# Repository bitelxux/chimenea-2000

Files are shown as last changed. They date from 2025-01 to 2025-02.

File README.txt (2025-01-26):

# libraries proved to work

Used library      Version Path
ArduinoJson       5.13.5  /home/cnn/Arduino/libraries/ArduinoJson
btlx25                    /home/cnn/MEGA/dev/arduino/btlx25
ESP8266WiFi       1.0     /home/cnn/.arduino15/packages/esp8266/hardware/esp8266/3.1.2/libraries/ESP8266WiFi
ESP8266HTTPClient 1.2     /home/cnn/.arduino15/packages/esp8266/hardware/esp8266/3.1.2/libraries/ESP8266HTTPClient
ArduinoOTA        1.0     /home/cnn/.arduino15/packages/esp8266/hardware/esp8266/3.1.2/libraries/ArduinoOTA
EEPROM            1.0     /home/cnn/.arduino15/packages/esp8266/hardware/esp8266/3.1.2/libraries/EEPROM
NTPClient         3.2.1   /home/cnn/Arduino/libraries/NTPClient
DNSServer         1.1.1   /home/cnn/.arduino15/packages/esp8266/hardware/esp8266/3.1.2/libraries/DNSServer
ESP8266WebServer  1.0     /home/cnn/.arduino15/packages/esp8266/hardware/esp8266/3.1.2/libraries/ESP8266WebServer
WiFiManager       2.0.17  /home/cnn/Arduino/libraries/WiFiManager
ESP8266mDNS       1.2     /home/cnn/.arduino15/packages/esp8266/hardware/esp8266/3.1.2/libraries/ESP8266mDNS

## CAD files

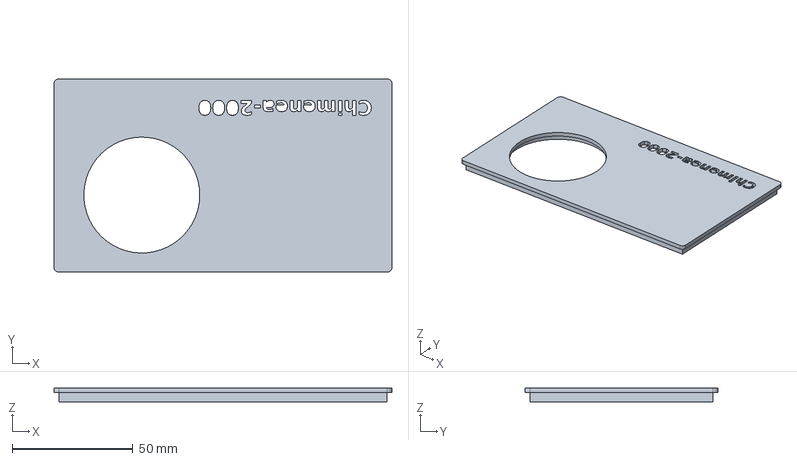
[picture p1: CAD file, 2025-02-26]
freecad/chimenea2000.FCStd
140.0 x 80.0 x 6.00 mm

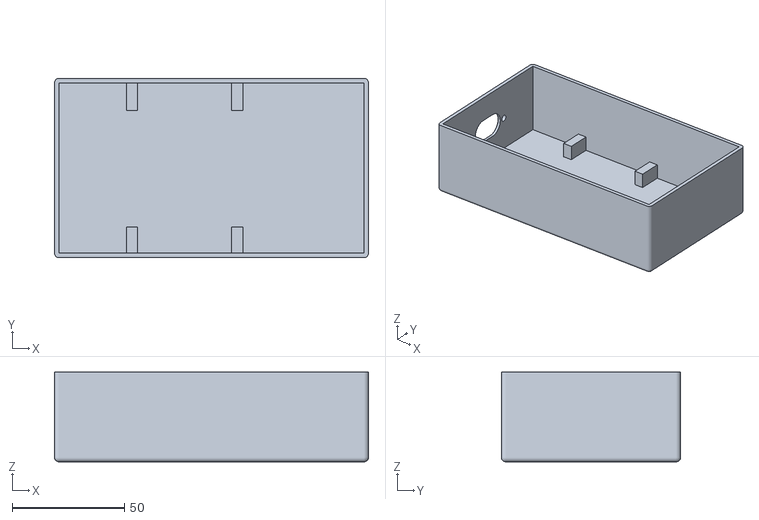
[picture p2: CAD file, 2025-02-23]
freecad/chimenea2000-Body.stl
140.0 x 80.0 x 40.0

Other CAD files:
freecad/tapa.3mf
freecad/tapa.stl

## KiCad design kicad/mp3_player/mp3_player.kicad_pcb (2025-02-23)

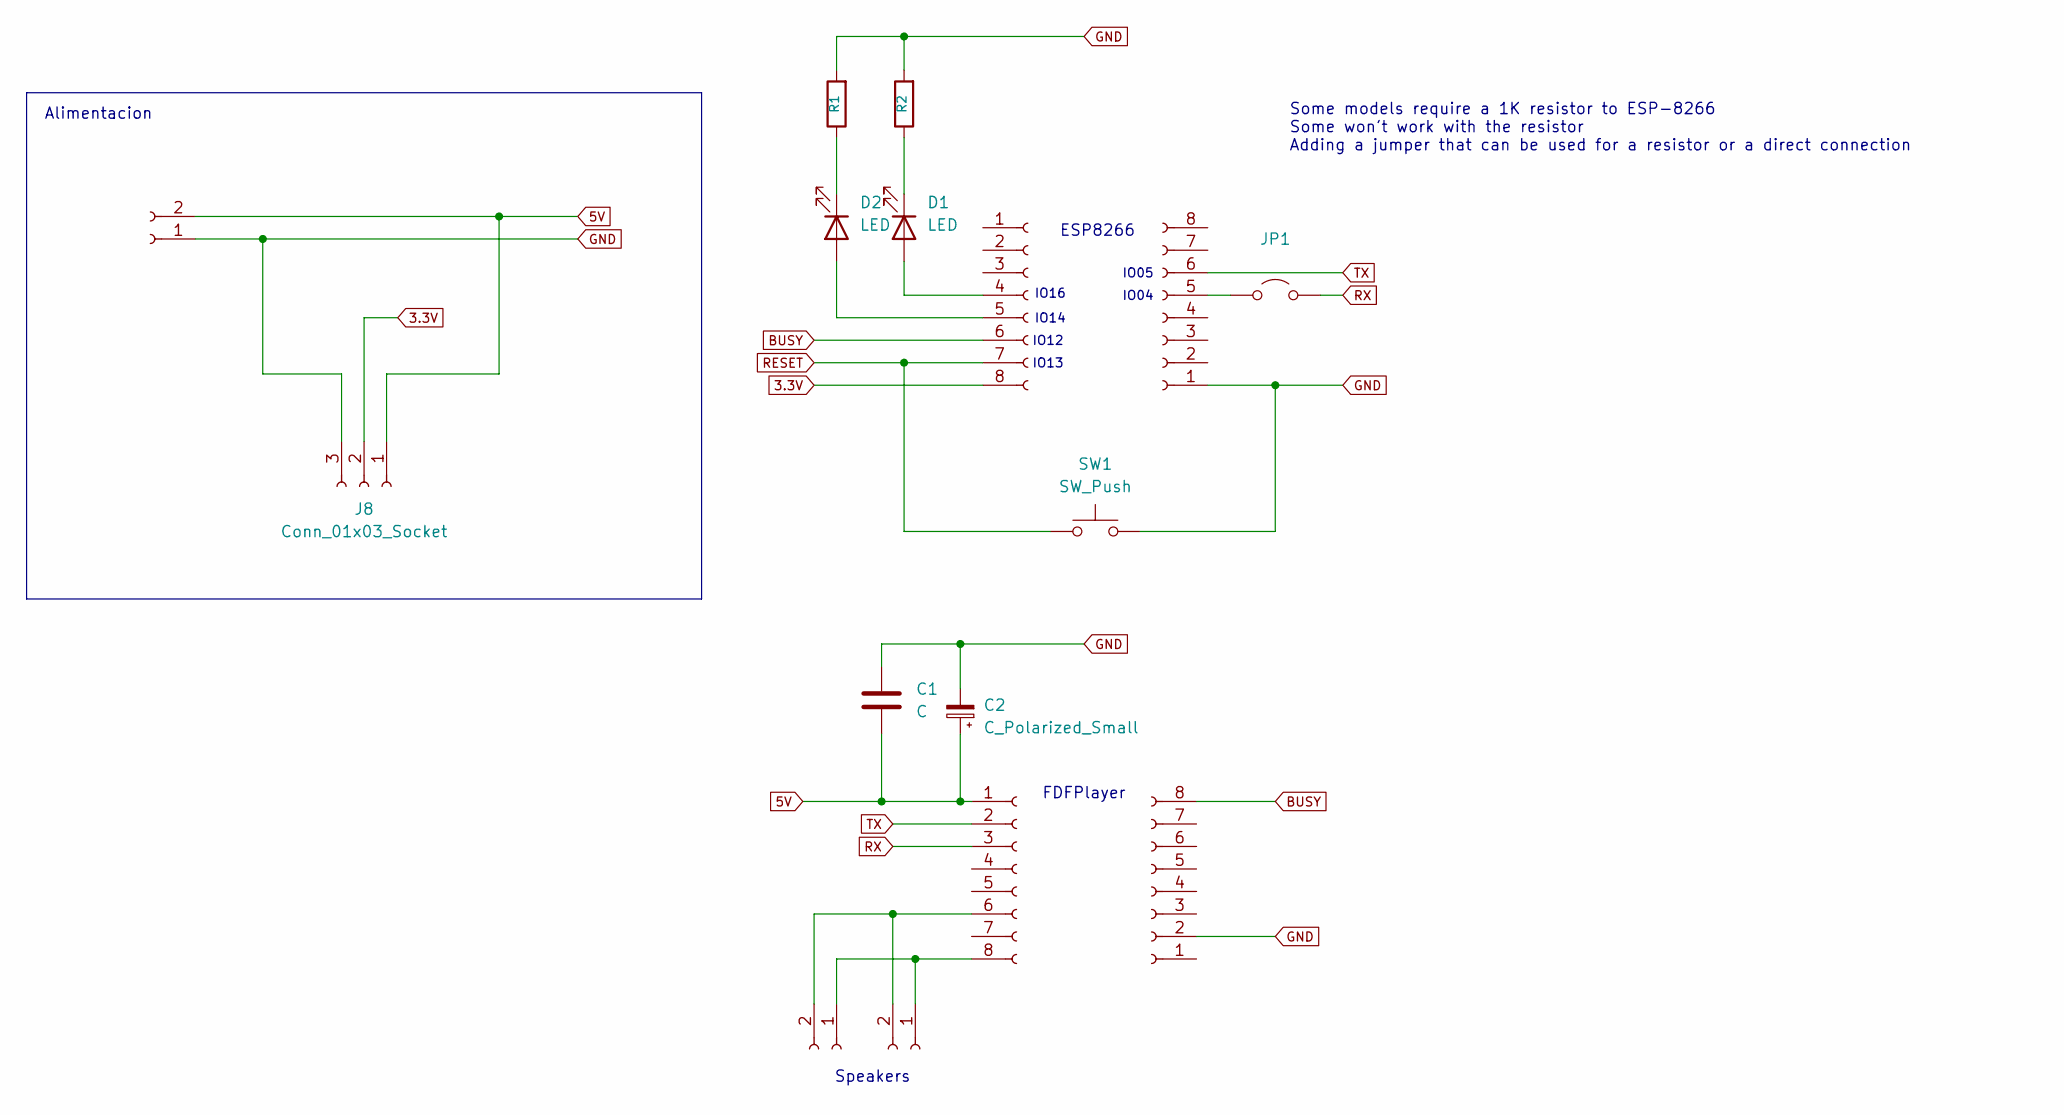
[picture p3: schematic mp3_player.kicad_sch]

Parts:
C1: C; C_Disc_D3.0mm_W1.6mm_P2.50mm
C2: C_Polarized_Small; CP_Radial_D7.5mm_P2.50mm
D1, D2: LED; LED_D5.0mm
J1: ESP8266-left; PinSocket_1x08_P2.54mm_Vertical
J2: ESP8266-right; PinSocket_1x08_P2.54mm_Vertical
J3: AC 220; JST_EH_B2B-EH-A_1x02_P2.50mm_Vertical
J4: player-left; PinSocket_1x08_P2.54mm_Vertical
J5: player-right; PinSocket_1x08_P2.54mm_Vertical
J6, J7: Conn_01x02_Socket; JST_EH_B2B-EH-A_1x02_P2.50mm_Vertical
J8: Conn_01x03_Socket; PinSocket_1x03_P2.54mm_Vertical
JP1: Jumper_2_Open; TestPoint_2Pads_Pitch5.08mm_Drill1.3mm
R1, R2: R; R_Axial_DIN0207_L6.3mm_D2.5mm_P7.62mm_Horizontal
SW1: SW_Push; SW_PUSH_6mm_H4.3mm

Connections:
3.3V: J1.8, J8.2
5V: C1.1, C2.1, J3.2, J4.1, J8.1
BUSY: J1.6, J5.8
GND: C1.2, C2.2, J2.1, J3.1, J5.2, J8.3, R1.2, R2.2, SW1.2
unnamed: D1.2 (A), J1.4
unnamed: D1.1 (K), R2.1
unnamed: D2.2 (A), J1.5
unnamed: D2.1 (K), R1.1
unnamed: J2.5, JP1.1 (A)
unnamed: J4.6, J6.2, J7.2
unnamed: J4.8, J6.1, J7.1
RESET: J1.7, SW1.1
RX: J4.3, JP1.2 (B)
TX: J2.6, J4.2

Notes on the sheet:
Alimentacion
Some models require a 1K resistor to ESP-8266 Some won't work with the resistor Adding a jumper that can be used for a resistor or a direct connection
IO14
IO04
ESP8266
FDFPlayer
IO13
IO16
Speakers
IO12
IO05

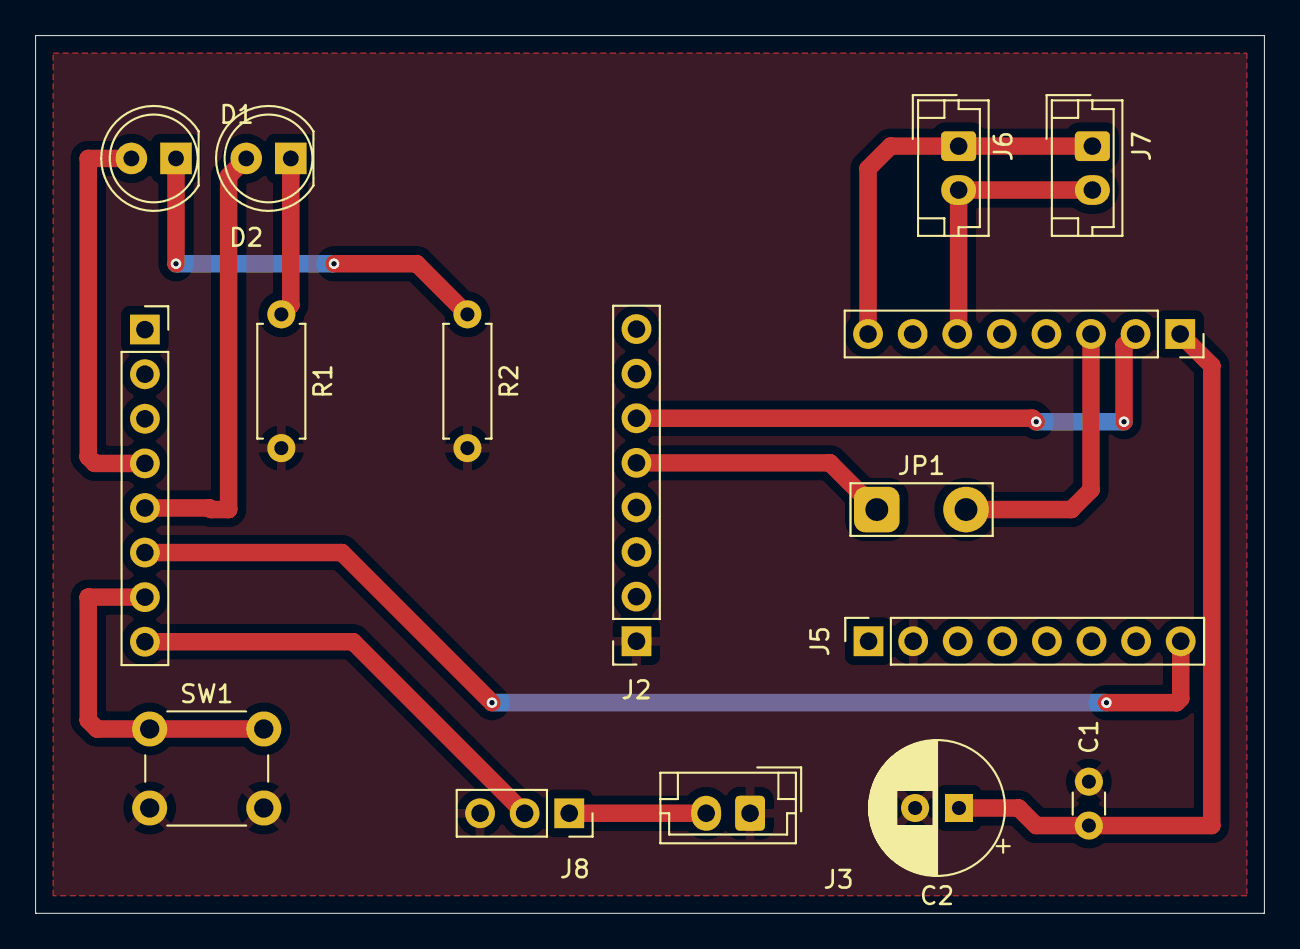
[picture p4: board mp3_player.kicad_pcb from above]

Board: 2 copper layers, 70.0 x 50.0 mm, 16 parts (0 on the bottom side), 14 nets.

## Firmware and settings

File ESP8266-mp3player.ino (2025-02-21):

//Libraries
#include <FS.h>
#include <LittleFS.h>
#include <ArduinoJson.h>  // 5.13.5 !!
#include <SoftwareSerial.h>
#include <DFRobotDFPlayerMini.h>

#include "config.h"

// tried many approaches to #include "btlx25/btlx25.h"b
// non worked. Workaround is to symlink the btlx25 folder to Arduino/libraries
#include <btlx25.h>

#include <web.h>
#include <player.h>

// Reset Button
#define RESET_BUTTON 14
unsigned long rb_last_change = 0;
int rb_required_time = 3;
boolean time_to_reset = false;

App *app = NULL;
Player *player = NULL;
WEBServer *webServer = NULL;

//flag for saving data
bool shouldSaveConfig = false;

//callback notifying us of the need to save config
void saveConfigCallback() {
  Serial.println("Should save config");
  shouldSaveConfig = true;
}

char buffer[200];

// This values  will depend on what the user configures
// on the  WifiManager on the first connection
char server[16] = "";
char log_server[30] = "";
char baseURL[30] = "";

//SoftwareSerial dfSerial(4, 5, false);
// DFRobotDFPlayerMini dfPlayer;

void scan_networks() {

  char *buffer = new char[1024];
  int n = WiFi.scanNetworks();
  char *connected = NULL;

  if (n == 0) {
    Serial.println("no networks found");
  } else {
    sprintf(buffer, "networks found:\n");
    for (int i = 0; i < n; ++i) {
      // Print SSID and RSSI for each network found

      if (WiFi.SSID(i) == WiFi.SSID()) {
        connected = "*";
      } else {
        connected = " ";
      }

      sprintf(buffer + strlen(buffer), "%d [%s] %-32s dBM %d (%d%%)\n",
              i + 1,
              connected,
              WiFi.SSID(i).c_str(),
              WiFi.RSSI(i),
              dBmtoPercentage(WiFi.RSSI(i)));
    }
  }
  //webServer.send(200, "text/plain", buffer);
  delete[] buffer;
}

void wifi_signal() {
  sprintf(buffer, "%s [%d]\n", WiFi.SSID(), WiFi.RSSI());
  //webServer.send(200, "text/plain", buffer);
}

int dBmtoPercentage(int dBm) {
  int quality;
  if (dBm <= RSSI_MIN) {
    quality = 0;
  } else if (dBm >= RSSI_MAX) {
    quality = 100;
  } else {
    quality = 2 * (dBm + 100);
  }

  return quality;
}


void readConfigFile() {
  Serial.println("mounting FS...");
  strcpy(server, "");

  if (SPIFFS.begin()) {
    Serial.println("mounted file system");
    if (SPIFFS.exists("/config.json")) {
      //file exists, reading and loading
      Serial.println("reading config file");
      File configFile = SPIFFS.open("/config.json", "r");
      if (configFile) {
        Serial.println("opened config file");
        size_t size = configFile.size();
        // Allocate a buffer to store contents of the file.
        std::unique_ptr<char[]> buf(new char[size]);

        configFile.readBytes(buf.get(), size);
        DynamicJsonBuffer jsonBuffer;
        JsonObject &json = jsonBuffer.parseObject(buf.get());
        json.printTo(Serial);
        if (json.success()) {
          Serial.println("\nparsed json");
          strcpy(server, json["server"]);
        } else {
          Serial.println("failed to load json config");
        }
      }
    }
  } else {
    Serial.println("failed to mount FS");
  }
}

void setup() {

  pinMode(BUSY_PIN, INPUT_PULLUP);
  pinMode(RESET, INPUT_PULLUP);
  pinMode(GREEN_LED, OUTPUT);
  pinMode(BLUE_LED, OUTPUT);

  digitalWrite(GREEN_LED, LOW);
  digitalWrite(BLUE_LED, LOW);

  Serial.begin(115200);

  Serial.println('\n\n');
  Serial.println('PROGRAM STARTING');

  delay(1000);

  if (!LittleFS.begin()) {
        app->log("LittleFS mount failed");
        ESP.restart();
  }

  EEPROM.begin(EEPROM_SIZE);

  app = new App(BOARD_ID, "http://192.168.1.104:8888", BLUE_LED);

  unsigned short boots = app->incBoots();
  sprintf(buffer, "boot: %d\n", boots);
  app->log(buffer);

  //readConfigFile();
  //WiFiManagerParameter pserver(SERVER_LABEL, "Server IP", server, 16);

  //set config save notify callback
  //app->wifiManager->setSaveConfigCallback(saveConfigCallback);

  if (app->startWiFiManager()) {
      Serial.println("Connected to WiFi");
  }

  player = new Player(app);
  
  //save the custom parameters to FS
  /*
  if (shouldSaveConfig) {
    Serial.println("saving config");
    DynamicJsonBuffer jsonBuffer;
    JsonObject &json = jsonBuffer.createObject();
    json["server"] = server;

    File configFile = SPIFFS.open("/config.json", "w");
    if (!configFile) {
      Serial.println("failed to open config file for writing");
    }

    json.printTo(Serial);
    json.printTo(configFile);
    configFile.close();
    //end save
  }
  */

  webServer = new WEBServer(app);
  webServer->registerPlayer(player);
  webServer->start();
}

void resetWIFI() {
  sprintf(buffer, "WIFI networks will be reset and board rebooted NOW");
  app->log(buffer);
  _resetWifi();
}

void _resetWifi() {
  app->log("reset WIFI networks");
  app->resetWIFI();
  ESP.restart();
}

void check_reset() {
    static int lastPressed = digitalRead(RESET);
    static bool pressed = false;

    if (digitalRead(RESET) == LOW) {
        if( !pressed ) {
          pressed = true;
          lastPressed = millis();
        }          
        if (millis() - lastPressed > 4000) {
           app->log("Resetting WIFI. Please, configure on WifiManager.");
           for (int i=0; i<10; i++) {
             digitalWrite(BLUE_LED, i%2);
             delay(200);
           }
           resetWIFI();
        }
    }
    else {
      pressed = false;
    }    
}

void loop() {
  check_reset();
  app->attendTimers();
  webServer->handleClient();
  player->handle();
}

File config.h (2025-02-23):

// This is for each variable to use it's real size when stored
// in the EEPROM
//
//

#pragma pack(push, 1)

#define BOARD_ID "chimenea-2000"
#define VERSION "20250223.696"

//EEPROM
#define EEPROM_SIZE 1024

#define RSSI_MAX -50   // maximum strength of signal in dBm
#define RSSI_MIN -100  // minimum strength of signal in dBm

// WiFiManager parameteres
#define SERVER_LABEL "SERVER_IP"

// BOARD
#define RESET 13
#define GREEN_LED 16
#define BLUE_LED 14
#define BUSY_PIN 12

// to connect FDF player with SoftwareSerial
// on some modules dfplayer.tx -> esp8266.rx might require a 1K resistor
#define RX 4
#define TX 5

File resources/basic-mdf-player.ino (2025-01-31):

#include <SoftwareSerial.h>
#include <DFRobotDFPlayerMini.h>

#define BUSY_PIN 10
#define LED 12

SoftwareSerial mySerial(4, 5, false);
DFRobotDFPlayerMini myDFPlayer;

void setup() {

    pinMode(BUSY_PIN, INPUT_PULLUP);
    pinMode(LED, OUTPUT);

    Serial.begin(115200);
    mySerial.begin(9600);

    Serial.println("\nDFPlayer Mini Test");

    if (!myDFPlayer.begin(mySerial)) {
        Serial.println("DFPlayer Mini not detected!");
        while (true);
    }

    Serial.println("Player detected!");
    unsigned int totalFiles = myDFPlayer.readFileCounts(); // Get the total number of MP3 files in the SD card

    Serial.print("Total files detected: ");
    Serial.println(totalFiles);

    myDFPlayer.volume(30);
    //myDFPlayer.play(1);
}

void loop() {
  int busyState = digitalRead(BUSY_PIN);
  Serial.println(busyState);
  delay(10000);
}

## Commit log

2025-01-26 failed attempt to use local link to library
    [ESP8266-mp3player.ino]
2025-01-27 move millis_to_human to library
2025-01-27 fix buttons behaviour on mobile
2025-01-28 endpoint boardID. Also changing buffers to local scope
2025-02-02 moved to arduino 1.8.5 to be able to use FSLitle to upload files
2025-02-02 trying to upload FS from command line ... still failing
    [config.h]
2025-02-02 track number updated in web
2025-02-03 buttons back to their original color on push (android chrome)
2025-02-04 give serial time to settle. Also started kicad project
    [mp3_player.kicad_pcb, mp3_player.kicad_sch]
2025-02-07 adding reset button
    [mp3_player.kicad_pcb, mp3_player.kicad_sch]
2025-02-08 wifimanager only needs to be started once
    [mp3_player.kicad_pcb, mp3_player.kicad_sch]
2025-02-08 replacing timers for tickers
2025-02-09 revert global tickers. updateNTP takes too long and board was restarting
    [ESP8266-mp3player.ino, config.h]
2025-02-21 many changes. Main workaround to loop on faulty player
    [mp3_player.kicad_pcb, mp3_player.kicad_sch]
2025-02-22 explanation about loop workaround
    [config.h]
2025-02-23 wip board with ground plane
    [mp3_player.kicad_pcb]
2025-02-23 freecad box model
    [chimenea2000-Body.stl, chimenea2000.FCStd, tapa.stl]
2025-02-23 failed to fix play double shot
    [config.h]
2025-02-23 default track and audio changed
